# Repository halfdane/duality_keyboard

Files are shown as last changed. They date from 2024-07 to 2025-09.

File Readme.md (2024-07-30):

# The Duality Keyboard

Generated using ergogen:

Switch plate looks like this

To generate this, run `make`. That'll generate a whole bunch of svg files in `generated_files/outlines`. 
They obviously need quite a bit of postprocessing before they can be sent to a lasercutter, so in `to_laser` you can find all the files I used to lasercut the veneer layers.

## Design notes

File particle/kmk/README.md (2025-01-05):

Cirquitpython-based firmware for duality/particle

Using kmk, it's supporting the integrated touchpad (with automagic layer switching) as well as most of miryoku.

There are some notable deviations from miryoku, however: 
- Thumb key combos are global, not dependent on the current layer
- Tap both left thumb keys: ESCAPE
- Hold both left thumb keys: MOUSE-Layer
- Tap both right thumb keys: DELETE
- Hold both right thumb keys: FN-Layer

There's no need to build it, just copy it over after installing cirquitpython on the device.
Or run `make` to copy over the necessary files from kmk as well.

## Development
Usually circuitpython will offer the device for mounting as a USB mass storage - this is disabled in the boot.py.
To mount the board, keep a thumb key pressed on the side with the USB cable while the board boots (plug out, then in).

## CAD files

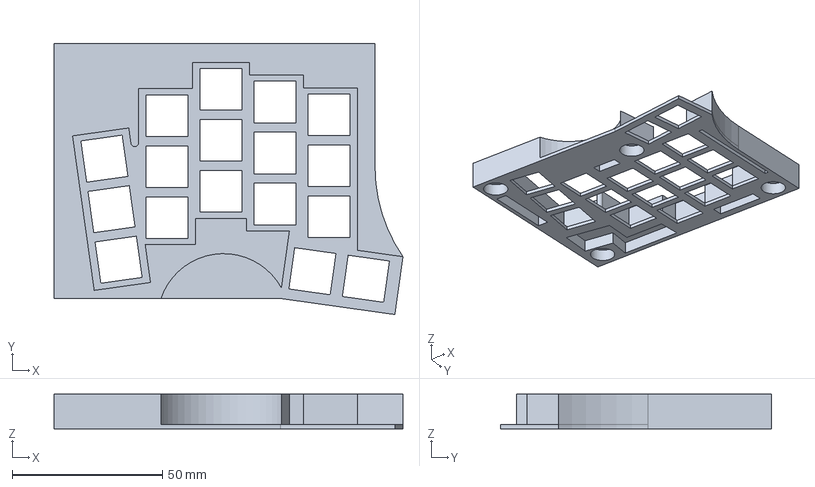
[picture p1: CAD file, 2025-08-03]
wave/case/wave_case.FCStd
116.3 x 90.3 x 11.5 mm

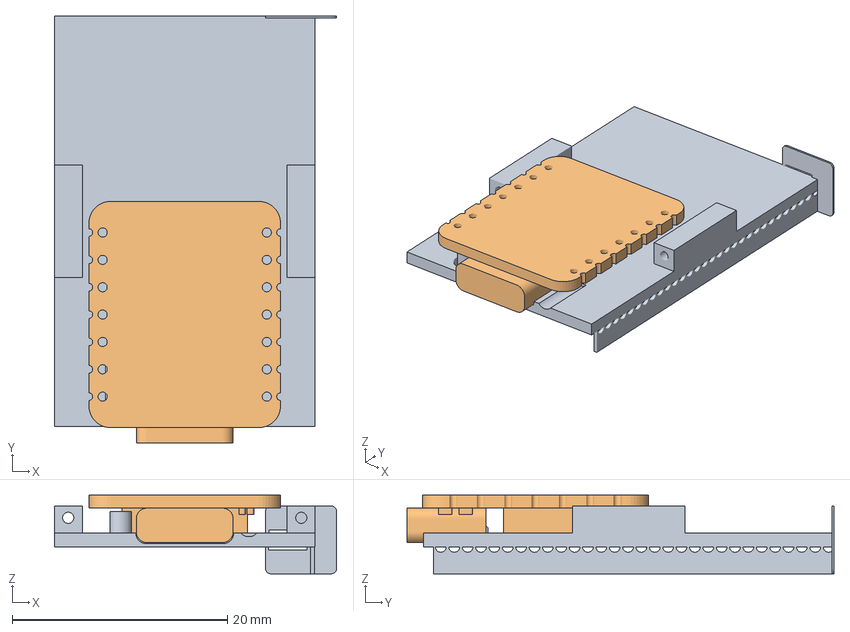
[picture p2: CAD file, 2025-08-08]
wave/case/xiao_fit/xiao_fit_2.FCStd
26.2 x 39.6 x 7.30 mm
Bottom
SeeedXiao-01

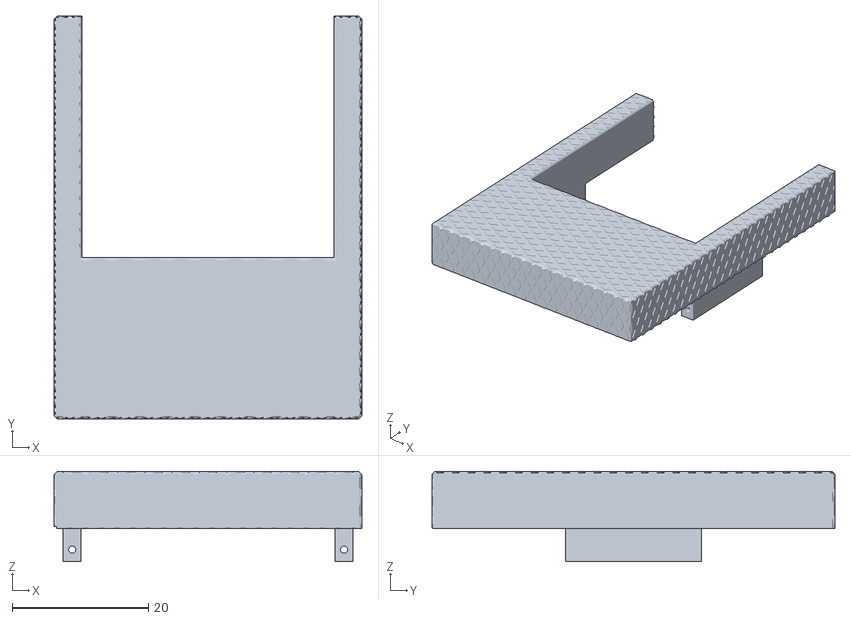
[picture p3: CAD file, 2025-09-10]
wave_keywell.stl
45.1 x 59.1 x 13.2

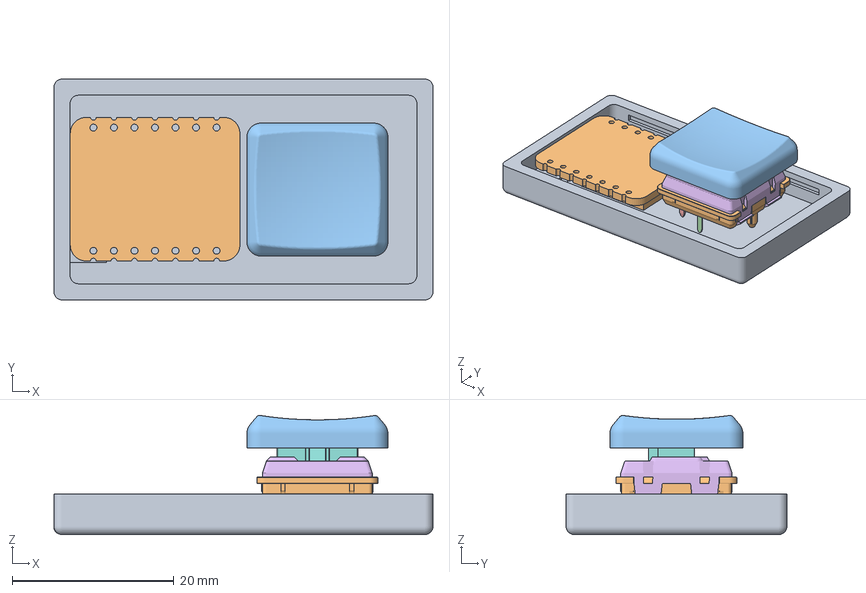
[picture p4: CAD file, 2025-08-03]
wave/case/xiao_fit/xiao_fit.FCStd
46.9 x 27.3 x 14.7 mm
BodyCase
bottom_stabilizer
contact
pin1
pin2
top_stabilizer
stabilizer
stem_stabilizer
shrunken_spring
SeeedXiao-01
MBK_Keycap_-_1u

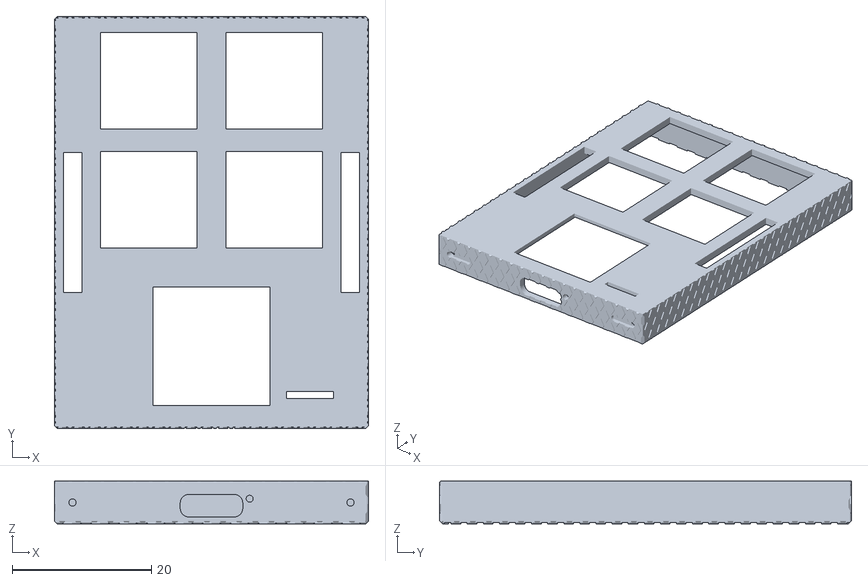
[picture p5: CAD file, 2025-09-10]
wave_case.stl
45.1 x 59.1 x 6.15

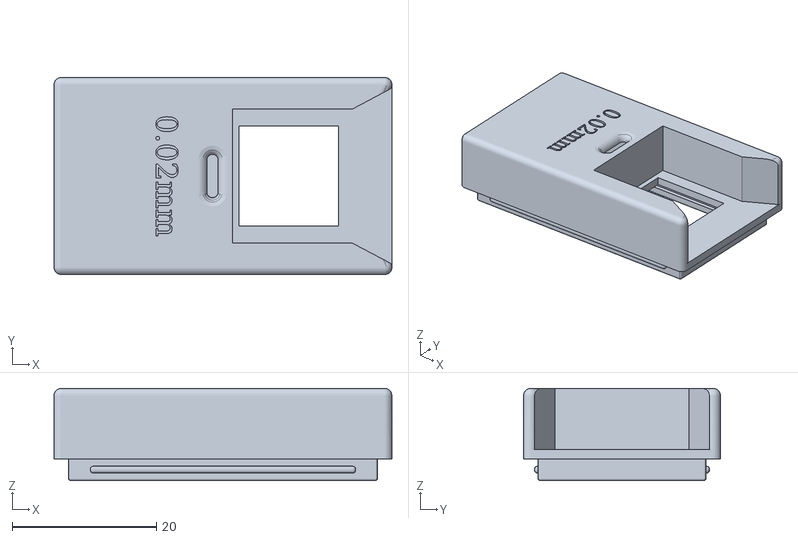
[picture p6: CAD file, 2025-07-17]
wave/case/xiao_fit/BodyLid (0.02).stl
46.9 x 27.3 x 12.8

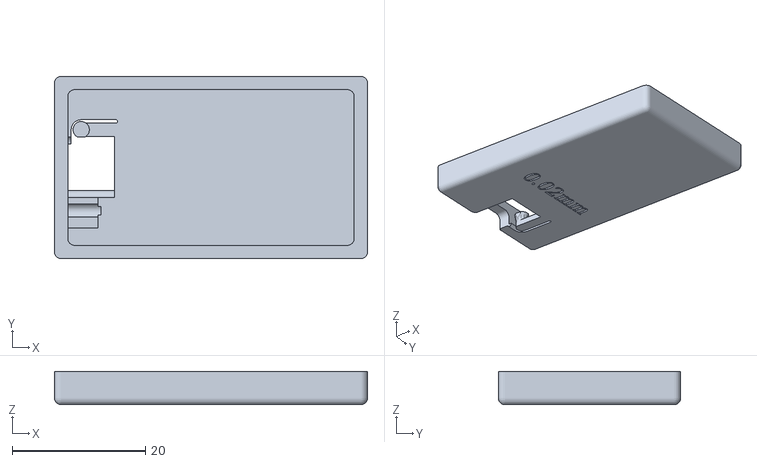
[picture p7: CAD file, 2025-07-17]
wave/case/xiao_fit/BodyCase (0.02).stl
46.9 x 27.3 x 5.00

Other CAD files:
wave/case/xiao_fit/BodyCase (0.01).stl
wave/case/xiao_fit/BodyLid (0.01).stl

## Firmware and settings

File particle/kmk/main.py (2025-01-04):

import board
from kb import KMKKeyboard
keyboard = KMKKeyboard()

from kmk.modules.split import Split, SplitType, SplitSide
split = Split(
    data_pin=keyboard.SPLIT_RX,
    data_pin2=keyboard.SPLIT_TX,
    uart_flip=True,
    use_pio=True)
keyboard.modules.append(split)

scan = None
try:
    from cirque import Cirque   
    import busio
    cirque = Cirque(busio.I2C(keyboard.CIRQUE_SCL, keyboard.CIRQUE_SDA))
    keyboard.modules.append(cirque)

    from motions import MotionScanner
    scan = MotionScanner(keyboard,
                 invert_x=False, invert_y=True, swap_xy=True,
                 tap_timeout=100, fling_min_velocity=15,
                 scroll_zone_percentage=10, scroll_sensitivity=5, invert_scroll=True)
    cirque.set_motionscanner(scan)
except RuntimeError:
    print("No cirque found - maybe wrong side") 

from miryoku import miryokufy
miryokufy(keyboard, scan)

# keyboard.debug_enabled = True
if __name__ == '__main__':
    keyboard.go()

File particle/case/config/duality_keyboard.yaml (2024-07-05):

##########################################
###
###     Given conditions:
###     - Each veneer sheet is 0.5mm thick
###     - Initial tests show that single veneer sheets aren't stable enough for cutting, 
###         so now each layer consists of two veneer sheets glued together as a 2-ply
###
###     - Height of USB-hole: 3mm (3 layers)
###     - Height/width of halves'/mouse connectors holes: 5mm/10mm (5 layers)
###     - M2-Screws and inlets
###     - Kailh choc switches
###     - Keycaps are 17mmx16mm
###     - Keycaps are NOT 18mmx18mm as usual!!
###     - Rubber bumpers are 4mm radius
###     - Magnets have 5mm radius and almost 2mm thickness (2 layers)
###     - Cirque Trackpad 40 - 39mm overlay / 41mm overlay lip
###       Case needs a bit space around, so maybe 43mm in total?
###       => 19.5mm overlay hole radius
###       => 20.5mm overlay lip hole radius
###       => 21.5mm outer casing radius
###
##########################################

units:
  # MY KEYCAPS: 17.5mmx16.5mm
  # cx and cy:  18.0mmx17.0mm for kailh choc
  kx: cx
  ky: cy
  # with padding
  px: kx + 1
  py: ky + 1

  # size of holes in switch plate - a bit smaller to account for laser kerf
  sh: 13.9

  rp2040_body_width: 23.5
  rp2040_body_height: 18

  thumb_rotation: -8
  pinky_rotation: 8

  m2_screw_radius: 1
  m2_head_radius: 1.8
  m2_inlet_radius: 1.5
  m2_outer_distance: 3

  rubber_bumper_radius: 4

  magnet_radius: 5.1

  symbols_radius_recess: 4
  symbols_radius_piece: 4.15

  base_width: 107
  base_height: 85

  middle_stagger: 0.7ky
  
  keyboard_tl_x: 0.5*base_width - rp2040_body_width + m2_outer_distance-1
  keyboard_tl_y: 0.5*base_height - middle_stagger-1

  connector_width: 10
  connector_length: 6
  
  cirque_case_radius: 44/2

points:
  zones:      
    symbol.anchor:
      shift: [(rp2040_body_width + m2_outer_distance)/2, -base_height/2-middle_stagger+m2_outer_distance]
    keyboard_tl.anchor:
      shift: [keyboard_tl_x, keyboard_tl_y]

    matrix:
      key:
        padding: 1ky
        spread: 1kx

      columns:
        pinky.key.splay: pinky_rotation
        ring.key.splay: -pinky_rotation
        ring.key.stagger: middle_stagger
        middle.key.stagger: 0.5ky
        index.key.stagger: -0.25ky
        inner.key.stagger: -0.25ky
      rows:
        bottom:
        home: 
        top: 
    thumb:
      anchor:
        ref: matrix_inner_bottom
        shift: [-6.5, -18]
        rotate: thumb_rotation
      columns:

        middle:
          key.name: thumb_middle
          key.origin: [-0.5U, -0.3U]
        reachy:
          key.name: thumb_reachy
          key.origin: [-0.5U, -0.3U]

outlines:
  _base:
    - what: rectangle
      size: [base_width, base_height]
      corner: 1
      where:
        ref: keyboard_tl
  
  ### holes for magnets to hold the two sides together when transporting
  _magnet_hole_top_left:
    - what: circle
      radius: magnet_radius
      where:
        shift: [-base_width/2+magnet_radius+m2_outer_distance, base_height/2-magnet_radius-(m2_outer_distance*2/3)]
        ref: keyboard_tl
  _magnet_hole_top_right:
    - what: circle
      radius: magnet_radius
      where:
        shift: [base_width/2-magnet_radius-m2_outer_distance, base_height/2-magnet_radius-(m2_outer_distance*2/3)]
        ref: keyboard_tl
  _magnet_hole_bottom_left:
    - what: circle
      radius: magnet_radius
      where:
        shift: [-base_width/2+magnet_radius+m2_outer_distance/2, -base_height/2+magnet_radius+(m2_outer_distance*2/3)]
        ref: keyboard_tl
  _magnet_holes: [
    _magnet_hole_top_left,
    _magnet_hole_top_right,
    _magnet_hole_bottom_left,
  ]
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

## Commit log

2022-06-13 initial layout
    [demo.dxf]
2022-06-13 now with touchpad and a plate
    [demo.dxf, intersected_outline.dxf, keys.dxf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]
2022-06-13 remove generated files from git
    [demo.dxf, intersected_outline.dxf, keys.dxf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]
2022-06-13 add the right-sized switch holes and a shaped switch plate
2022-06-14 make space for the usb cable
2022-06-14 introduce entry to cable tunnel
2022-06-14 make touchpad-hole slightly larger
2022-06-14 add screw holes
2022-06-21 use smaller footprint for keys
2022-10-19 ordered the plate at laserboost
2024-05-27 decide hole sizes
2024-05-29 switch to two thumb buttons
2024-06-02 clean up choc top frame
2024-06-07 introduce connector holes
2024-06-08 prepare second test burn
    [duality_keyboard.yaml]
2024-06-08 add laser strength area
2024-06-13 adjust connectors and add touchpad magnet
2024-06-13 add more magnets to the top layers
2024-06-13 adjust rp2040 cutout to keep solder pads usable
2024-06-13 top layer of switch pad doesn't have screw holes - hopefully they can stay below
    [duality_keyboard.yaml]
2024-06-14 prepare next cut
2024-06-14 add outer frame for checking
2024-06-20 some more connector fiddling
2024-06-20 reposition thumb screws
2024-06-21 adjust magnets
2024-06-21 first experiment with cirque case
2024-06-21 touchpad case
2024-06-26 fix outline where circle and thumb cluster meet
    [duality_keyboard.yaml]
2024-06-29 next lasering
2024-07-05 add a little recess for switches to clamp onto
2024-07-05 additional switchplate layer without recess, just in case the recesses are too much
2024-07-30 move files for case to its own subdir
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2025-01-05 automatic holding from the touchpad has interferred with keyboard mouse buttons. Reverting everything to simply support tap gestures.
2025-01-09 when following logs, just try to access any device that's there :/
2025-01-11 include newer version of circuitpython - both versions seem to work equally good, so i'll probably switch to the newer version completely eventually
2025-01-12 wait a tiny bit before trying to mount the board
2025-01-13 switch to matrix layout to introduce zmk studio capabilities
2025-01-13 matrix transform resembles soldering matrix now
2025-01-18 let's see if the split wired branch works
2025-01-19 be able to fiddle with uart pins - I have the feeling that I may have switched RX and TX
2025-01-20 switch to vanilla miryoky=u for ferris
2025-01-22 reduce uart speed for communication between halves to stabilize the connection
2025-01-23 move rp2040 definition over here so it's easier to follow wired split development
2025-01-23 fetch the uart fifo changes for zephyr
2025-01-23 enable i2c, mouse and pointing features
2025-01-23 configure i2c pins for cirque communication
2025-01-23 maybe putting the i2c=y everywhere helps?
2025-01-23 reducing i2c speed at least allows the board to boot
2025-01-24 disable glidepoint for now - seems like the DR-Pin isn't opional :/
2025-01-25 No need to patch miryoku after switching to own fork
2025-01-28 cirque works with dr pin
2025-02-09 switch to my own branch for simpler testing of PRs
2025-02-24 configure clamp values for absolute mode
2025-04-21 return to zmk main, now that the wired split code is merged
2025-07-17 initial fitting test print
    [BodyCase (0.01).stl, BodyCase (0.02).stl, BodyLid (0.01).stl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]
2025-08-03 more experiments with freecad
    [wave_case.FCStd, xiao_fit.FCStd, xiao_fit_2.FCStd]
2025-08-03 first attempts with build123d
    [Kailh_PG1353.STEP, XIAO-nRF52840 v15.step, red.step]
2025-08-08 getting the hang of build123d
    [Kailh_PG1353.STEP, XIAO-nRF52840 v15.step, red.step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]
2025-08-11 position model right side up and add bottom plate
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2025-09-01 lift xiao away from bottom to make usb hole more stable
2025-09-01 lift power switch away from bottom
2025-09-01 adjust size of clipper-pin and reposition keys so as to not interfere with the walls
2025-09-09 prototype finished
    [wave_case.stl, wave_keywell.stl]
2025-09-10 adjust sizing of switches with consequences for the dependent models
    [wave_case.stl, wave_keywell.stl]
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2025-09-14 extract switch positions into its own file
2025-09-14 add little protrusions to hold the connectors
2025-09-14 add electric pins to switches and create left and right parts of board
2025-09-14 adjust the little protrusions as well as the connector positions
2025-09-15 translate switch positions globally instead of locally
2025-09-15 add first attempt at bottom plate
2025-09-16 make case outline smoother
2025-09-19 usb-cutter should cut in both directions
2025-09-22 change dimension of switches to vectors
2025-09-23 adjust xiao positioning and usb holes
2025-09-24 add physical support for xiao as well as reset button
2025-09-24 make case slimmer by recessing switch posts into bottom-plate, along with necessary adjustments. Introduce powerswitch
2025-09-27 get rid of ribs on bottom plate and refactor the reset lever
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2025-09-29 simplify clip-design and add holding-clips for plates.
2025-10-01 refactor bumper holder dimensions and cleanup extrusions
2025-10-02 positioning of powerswitch and xiao
2025-10-02 reposition xiao and power switch, refactor connector depressions
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2025-10-03 adjust outline because battery wouldn't fit otherwise. Add battery and magnets
2025-10-03 adjust wire connector to xiao to account for new y size
2025-10-03 using a nail as a pin, which required a bit of shuffling
2025-10-04 make slightly more room for one of the magnets
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2025-10-04 make outline and key positions parameterizable so other switches and caps can be supported as well
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2025-11-03 switch fully to ergogen based layout
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2025-11-07 put switch clearance not into switch but when cutting out the hole
2025-11-08 introduce parent class for case dimensions as well as a positioning of space invaders
2025-11-10 place pin a tiny bit more topwards
